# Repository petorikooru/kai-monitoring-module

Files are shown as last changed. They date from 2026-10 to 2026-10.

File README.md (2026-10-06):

# KAI Monitoring Device

---

This is a repository for Monitoring Device. Built using ESP-IDF v6 Framework.

## External Dependencies

- LovyanGFX
- LVGL

## Hardware Needed

- Eepever 1210N (Through RJ45 RS485 Port)
- SHT45 Temperature and Humidity Sensor
- TTL to RS485 Module
- ST7796 + XPT2046 Resistive Touch LCD Display

## Todo List

- [ ] PCB Design and Printing
- [ ] Full 24h testing

## Credits

- Alexander Kuznetsov for YD ESP32-S3 Schematic and Footprint

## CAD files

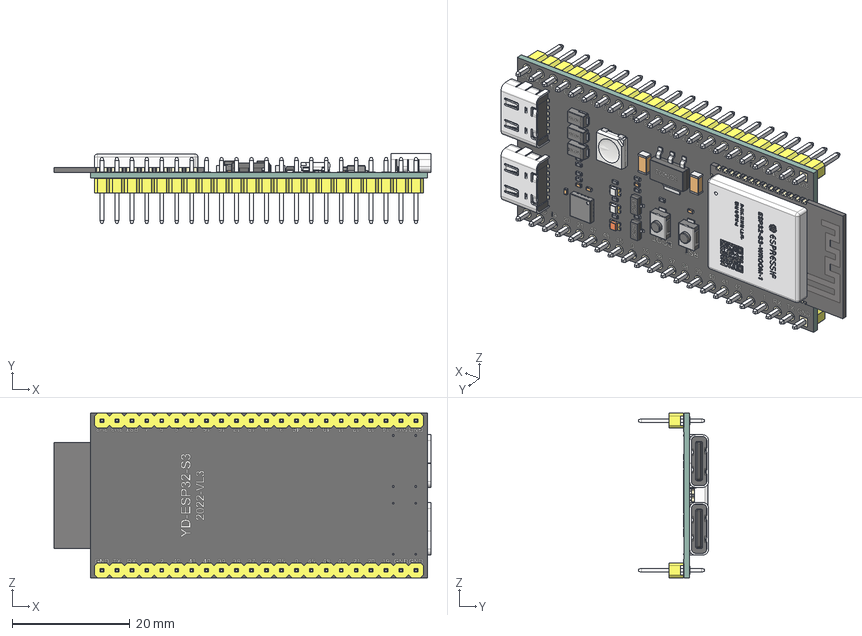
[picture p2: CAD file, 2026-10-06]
hardware/YD-ESP32-S3-main/YD-ESP32-S3.step
64.0 x 11.9 x 28.0 mm
PCB
ESP-S3-WROOM_via v3 x 26
ESP32-S3-WROOM_shell v11
ESP32-S3-WROOM_body v12
ESP-S3-WROOM_via v3(镜像) x 14
USB Connector Type C female 6pin x 2
DO220AA x 3
WS2812B
Light
Anode Bottom
Cathode Bottom
Anode
Cathode
Base
Light_1
Anode Bottom_1
Cathode Bottom_1
Anode_1
Cathode_1
Base_1
Light_2
Anode Bottom_2
Cathode Bottom_2
Anode_2
Cathode_2
Base_2
SOT-223
SOT-23 x 2
3x4x2mm - 2 Pad x 2
22way PCB Header x 2

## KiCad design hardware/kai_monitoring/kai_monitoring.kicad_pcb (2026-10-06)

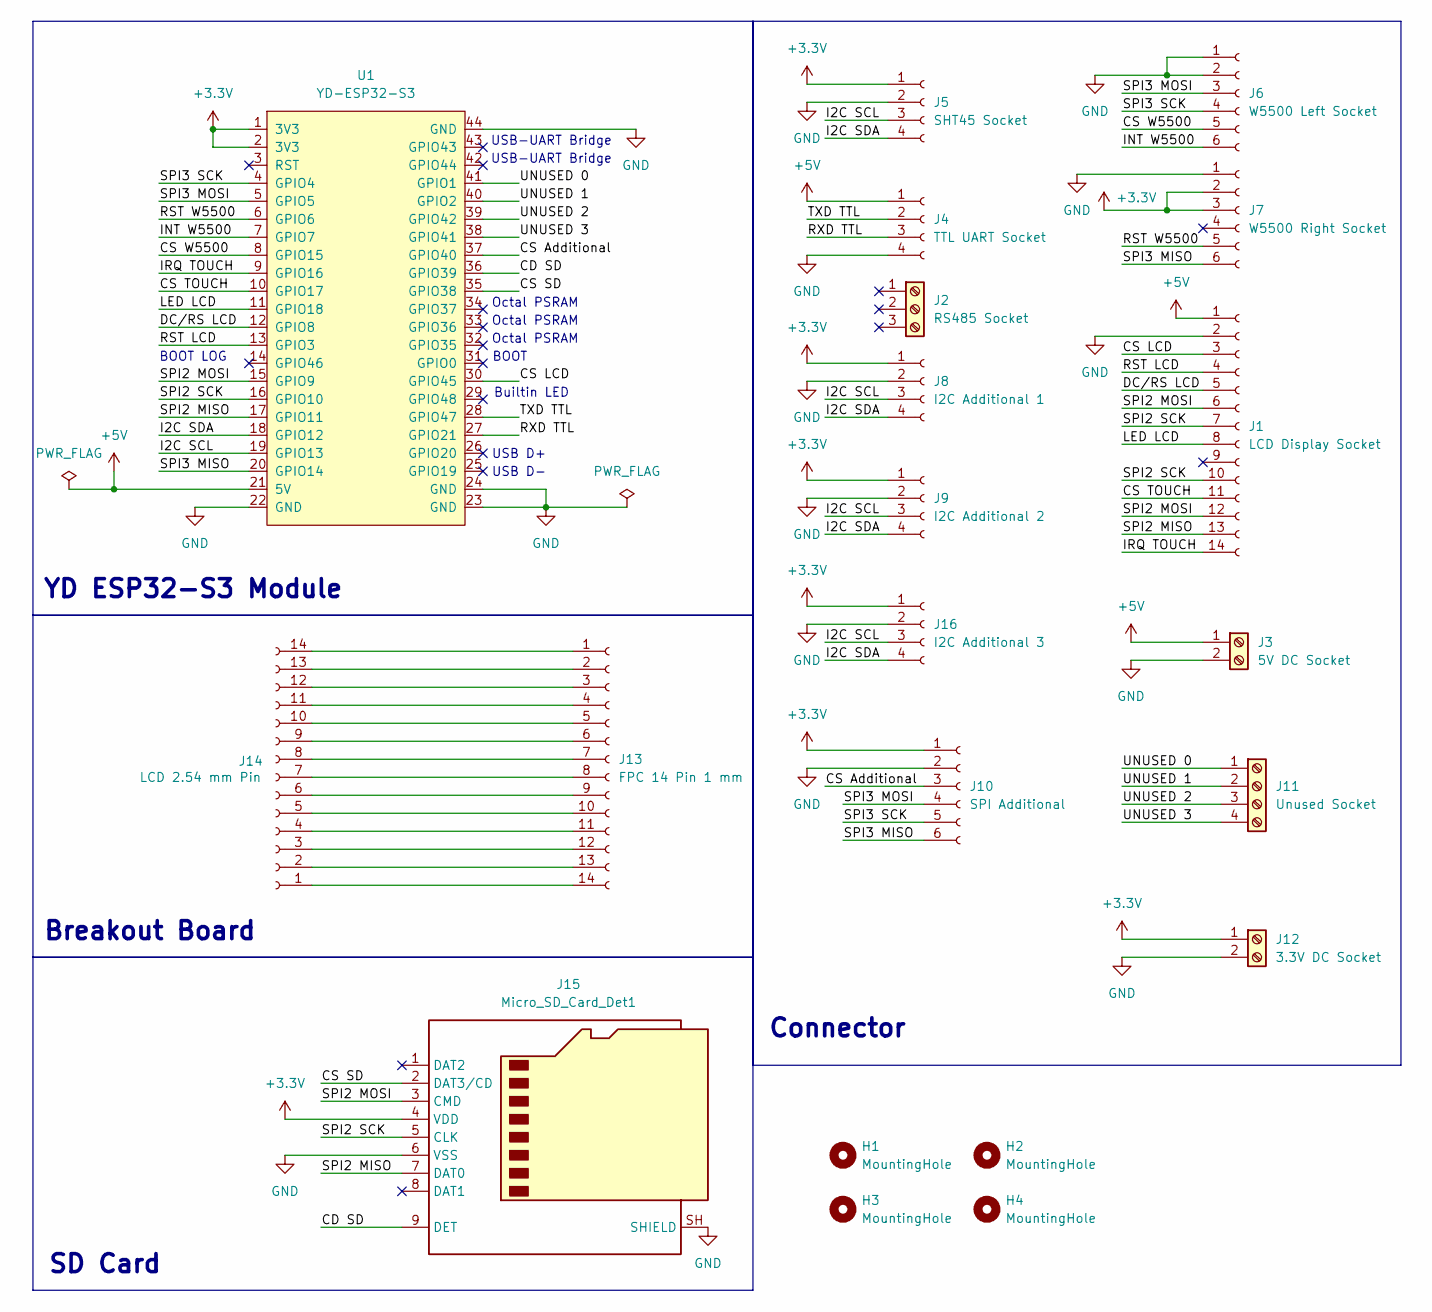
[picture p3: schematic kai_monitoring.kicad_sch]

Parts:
H1, H2, H3, H4: MountingHole; MountingHole_3.2mm_M3_Pad
J1: LCD Display Socket; Molex_200528-0140_1x14-1MP_P1.00mm_Horizontal
J2: RS485 Socket; TerminalBlock_Phoenix_MKDS-1,5-3_1x03_P5.00mm_Horizontal
J3: 5V DC Socket; TerminalBlock_Phoenix_MKDS-3-2-5.08_1x02_P5.08mm_Horizontal
J4: TTL UART Socket; PinSocket_1x04_P2.54mm_Vertical
J5: SHT45 Socket; PinSocket_1x04_P2.54mm_Vertical
J6: W5500 Left Socket; PinSocket_1x06_P2.54mm_Vertical
J7: W5500 Right Socket; PinSocket_1x06_P2.54mm_Vertical
J8: I2C Additional 1; PinSocket_1x04_P2.54mm_Vertical
J9: I2C Additional 2; PinSocket_1x04_P2.54mm_Vertical
J10: SPI Additional; PinSocket_1x06_P2.54mm_Vertical
J11: Unused Socket; TerminalBlock_Phoenix_MKDS-1,5-4_1x04_P5.00mm_Horizontal
J12: 3.3V DC Socket; TerminalBlock_Phoenix_MKDS-3-2-5.08_1x02_P5.08mm_Horizontal
J13: FPC 14 Pin 1 mm; Molex_200528-0140_1x14-1MP_P1.00mm_Horizontal
J14: LCD 2.54 mm Pin; PinSocket_1x14_P2.54mm_Vertical
J15: Micro_SD_Card_Det1; microSD_HC_Hirose_DM3AT-SF-PEJM5
J16: I2C Additional 3; PinSocket_1x04_P2.54mm_Vertical
U1: YD-ESP32-S3

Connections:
+3.3V: J5.1, J7.2, J7.3, J8.1, J9.1, J10.1, J12.1, J15.4 (VDD), J16.1, U1.1 (3V3), U1.2 (3V3)
+5V: J1.1, J3.1, J4.1, U1.21 (5V)
/CD SD: J15.9 (DET), U1.36 (GPIO39)
/CS Additional: J10.3, U1.37 (GPIO40)
/CS LCD: J1.3, U1.30 (GPIO45)
/CS SD: J15.2 (DAT3/CD), U1.35 (GPIO38)
/CS TOUCH: J1.11, U1.10 (GPIO17)
/CS W5500: J6.5, U1.8 (GPIO15)
/DC/RS LCD: J1.5, U1.12 (GPIO8)
/I2C SCL: J5.3, J8.3, J9.3, J16.3, U1.19 (GPIO13)
/I2C SDA: J5.4, J8.4, J9.4, J16.4, U1.18 (GPIO12)
/INT W5500: J6.6, U1.7 (GPIO7)
/IRQ TOUCH: J1.14, U1.9 (GPIO16)
/LED LCD: J1.8, U1.11 (GPIO18)
/RST LCD: J1.4, U1.13 (GPIO3)
/RST W5500: J7.5, U1.6 (GPIO6)
/RXD TTL: J4.3, U1.27 (GPIO21)
/SPI2 MISO: J1.13, J15.7 (DAT0), U1.17 (GPIO11)
/SPI2 MOSI: J1.6, J1.12, J15.3 (CMD), U1.15 (GPIO9)
/SPI2 SCK: J1.7, J1.10, J15.5 (CLK), U1.16 (GPIO10)
/SPI3 MISO: J7.6, J10.6, U1.20 (GPIO14)
/SPI3 MOSI: J6.3, J10.4, U1.5 (GPIO5)
/SPI3 SCK: J6.4, J10.5, U1.4 (GPIO4)
/TXD TTL: J4.2, U1.28 (GPIO47)
/UNUSED 0: J11.1, U1.41 (GPIO1)
/UNUSED 1: J11.2, U1.40 (GPIO2)
/UNUSED 2: J11.3, U1.39 (GPIO42)
/UNUSED 3: J11.4, U1.38 (GPIO41)
GND: J1.2, J3.2, J4.4, J5.2, J6.1, J6.2, J7.1, J8.2, J9.2, J10.2, J12.2, J15.6 (VSS), J15.SH (SHIELD), J16.2, U1.22 (GND), U1.23 (GND), U1.24 (GND), U1.44 (GND)
unnamed: J13.1, J14.14
unnamed: J13.2, J14.13
unnamed: J13.3, J14.12
unnamed: J13.4, J14.11
unnamed: J13.5, J14.10
unnamed: J13.6, J14.9
unnamed: J13.7, J14.8
unnamed: J13.8, J14.7
unnamed: J13.9, J14.6
unnamed: J13.10, J14.5
unnamed: J13.11, J14.4
unnamed: J13.12, J14.3
unnamed: J13.13, J14.2
unnamed: J13.14, J14.1

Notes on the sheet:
Octal PSRAM
USB D-
BOOT LOG
USB D+
BOOT
SD Card
USB-UART Bridge
Breakout Board
YD ESP32-S3 Module
Builtin LED
Connector

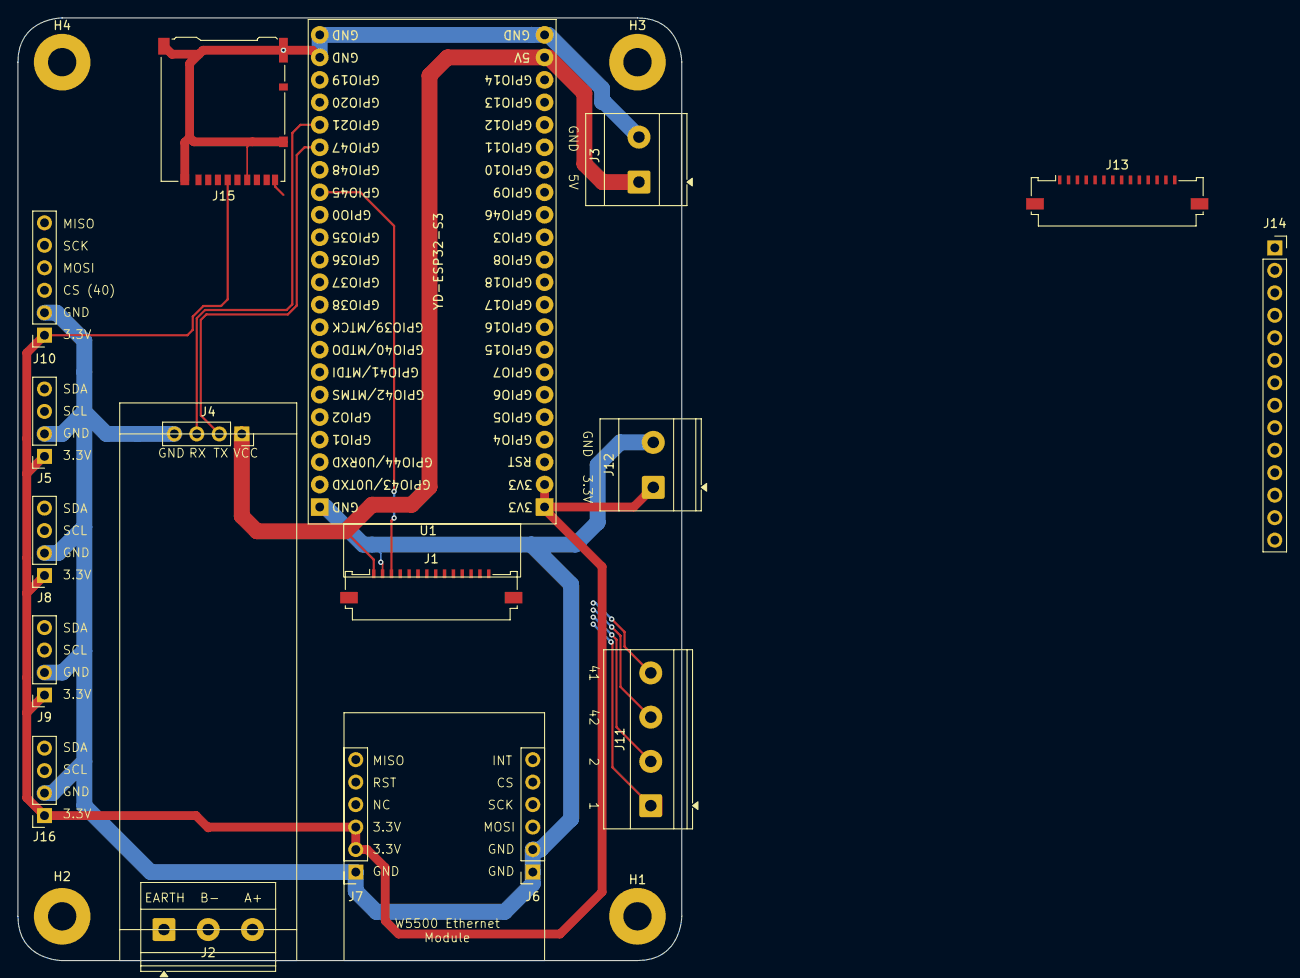
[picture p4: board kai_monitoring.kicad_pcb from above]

Board: 2 copper layers, 75.0 x 106.5 mm, 21 parts (0 on the bottom side), 43 nets.

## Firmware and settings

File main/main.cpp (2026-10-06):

#include "net_eth.h"
#include "nvs_flash.h"
#include "driver/gpio.h"
#include "freertos/FreeRTOS.h"
#include "freertos/task.h"
#include "esp_log.h"
#include "driver/spi_master.h"
#include <cstdio>
#include "esp_event.h"
#include "esp_netif.h"

// Local Files //////////////////////////
#include "config.h"
#include "led_indicator.h"
#include "lcd_touch.h"
#include "sensor_sht45.h"
#include "eepever.h"
#include "ui.h"
#include "wifi.h"
#include "mqtt.h"
#include "ui_log.h"


static const char *TAG_START = "Startup";

static void sensor_task(void *arg)
{
    (void)arg;

    while (1) {
        float temp = 0;
        float hum = 0;
        esp_err_t err = sensor_sht45_read(&temp, &hum);

        if (err == ESP_OK) {
            esp_err_t mqtt_err = mqtt_set_readings(temp, hum);
            if (mqtt_err != ESP_OK) {
                ESP_LOGW(TAG_START, "MQTT sample: %s",
                         esp_err_to_name(mqtt_err));
            }

            if (ui_lock(0)) {
                char buf[32];

                snprintf(buf, sizeof(buf), "%.1f C", temp);
                ui_set_temp(buf);

                snprintf(buf, sizeof(buf), "%.1f %%", hum);
                ui_set_hum(buf);

                ui_push_trend((int)temp, (int)hum);
                ui_unlock();
            }

            led_switch(LED_TX);
        } else {
            if (ui_lock(0)) {
                ui_set_temp("err");
                ui_set_hum("err");
                ui_unlock();
            }

            led_switch(LED_ERR);
        }

        vTaskDelay(pdMS_TO_TICKS(2000));
    }
}

static void init_task(void *arg)
{
    (void)arg;

    ESP_LOGI(TAG_START, "Booting...");
    led_init();
    led_switch(LED_BOOT);

    lcd_touch_init();

    ESP_ERROR_CHECK(nvs_flash_init());
    ESP_ERROR_CHECK(esp_netif_init());

    esp_err_t err = esp_event_loop_create_default();
    if (err != ESP_OK && err != ESP_ERR_INVALID_STATE) {
        ESP_ERROR_CHECK(err);
    }

    ESP_ERROR_CHECK(eth_init());
    ESP_ERROR_CHECK(wifi_manager_init(eth_get_handle(), eth_get_netif()));
    ESP_ERROR_CHECK(mqtt_publisher_init(NULL));

    esp_err_t ep_err = epever_init();
    if (ep_err != ESP_OK) {
        ESP_LOGE(TAG_START, "EPever init: %s", esp_err_to_name(ep_err));
    }

    sensor_sht45_init();

    if (!ui_lock(portMAX_DELAY)) {
        ESP_LOGE(TAG_START, "UI lock failed");
        abort();
    }

    ui_init();
    ui_set_eth_retry_cb(eth_start_or_retry);
    ui_unlock();

    if (xTaskCreate(sensor_task, "sensor_task", 4096, NULL, 5, NULL) != pdPASS) {
        ESP_LOGE(TAG_START, "Sensor task creation failed");
        abort();
    }

    vTaskDelete(NULL);
}

extern "C" void app_main(void)
{
    xTaskCreate(init_task, "init_task", 8192, NULL, 5, NULL);
}

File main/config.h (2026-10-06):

#pragma once

#define LED_GPIO        48
#define SPI_MOSI_GPIO   9
#define SPI_MISO_GPIO   11
#define SPI_SCLK_GPIO   10
#define CS_LCD_GPIO     45
#define CS_ETH_GPIO     15
#define ETH_SPI_SCLK_GPIO 4
#define ETH_SPI_MOSI_GPIO 5
#define ETH_SPI_MISO_GPIO 14
#define CS_TCH_GPIO     17
#define ETH_INT_GPIO    7
#define ETH_RST_GPIO    6
#define TCH_IRQ_GPIO    16
#define TTL_TX_GPIO     19
#define TTL_RX_GPIO     20
#define I2C_SCL         13
#define I2C_SDA         12
#define LCD_RST         3
#define LCD_DC          8
#define LCD_LED         18

#define LCD_H_RES       320
#define LCD_V_RES       480

#define SHT45_ADDR      0x44

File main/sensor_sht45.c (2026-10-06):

#include "sensor_sht45.h"
#include "config.h"
#include "driver/i2c_master.h"
#include "freertos/FreeRTOS.h"
#include "freertos/task.h"

static i2c_master_bus_handle_t i2c_bus = NULL;
static i2c_master_dev_handle_t sht45_dev = NULL;

void sensor_sht45_init(void)
{
    i2c_master_bus_config_t bus_config = {};
    bus_config.i2c_port = I2C_NUM_0;
    bus_config.sda_io_num = (gpio_num_t)I2C_SDA;
    bus_config.scl_io_num = (gpio_num_t)I2C_SCL;
    bus_config.clk_source = I2C_CLK_SRC_DEFAULT;
    bus_config.glitch_ignore_cnt = 7;
    bus_config.flags.enable_internal_pullup = true;
    ESP_ERROR_CHECK(i2c_new_master_bus(&bus_config, &i2c_bus));

    i2c_device_config_t dev_config = {};
    dev_config.dev_addr_length = I2C_ADDR_BIT_LEN_7;
    dev_config.device_address = SHT45_ADDR;
    dev_config.scl_speed_hz = 100000;
    ESP_ERROR_CHECK(i2c_master_bus_add_device(i2c_bus, &dev_config, &sht45_dev));
}

esp_err_t sensor_sht45_read(float *temperature, float *humidity)
{
    uint8_t cmd = 0xFD; // high precision measure
    uint8_t data[6];

    esp_err_t err = i2c_master_transmit(sht45_dev, &cmd, 1, 100);
    if (err != ESP_OK) return err;

    vTaskDelay(pdMS_TO_TICKS(10));

    err = i2c_master_receive(sht45_dev, data, 6, 100);
    if (err != ESP_OK) return err;

    uint16_t t_raw = (data[0] << 8) | data[1];
    uint16_t rh_raw = (data[3] << 8) | data[4];

    *temperature = -45.0f + 175.0f * ((float)t_raw / 65535.0f);
    *humidity = -6.0f + 125.0f * ((float)rh_raw / 65535.0f);

    return ESP_OK;
}

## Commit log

2026-10-06 Initial project
    [YD-ESP32-S3.step, kai_monitoring.kicad_pcb, kai_monitoring.kicad_sch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]
2026-10-11 Updated the pcb
2026-10-13 Updated the pcb again
